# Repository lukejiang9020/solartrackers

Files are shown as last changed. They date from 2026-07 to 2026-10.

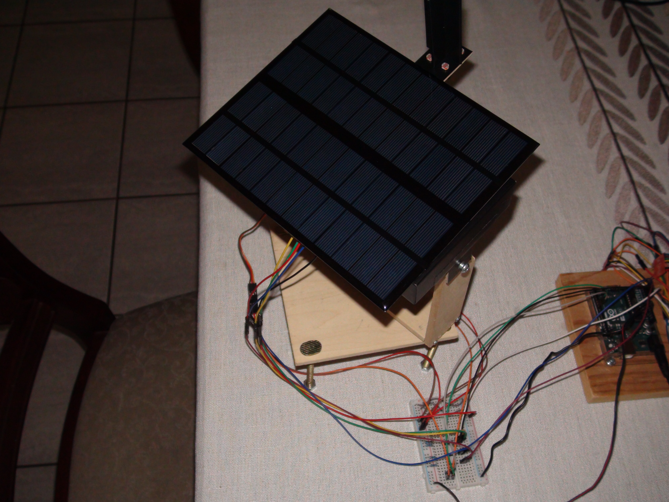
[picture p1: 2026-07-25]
imgs/DSC03407.JPG

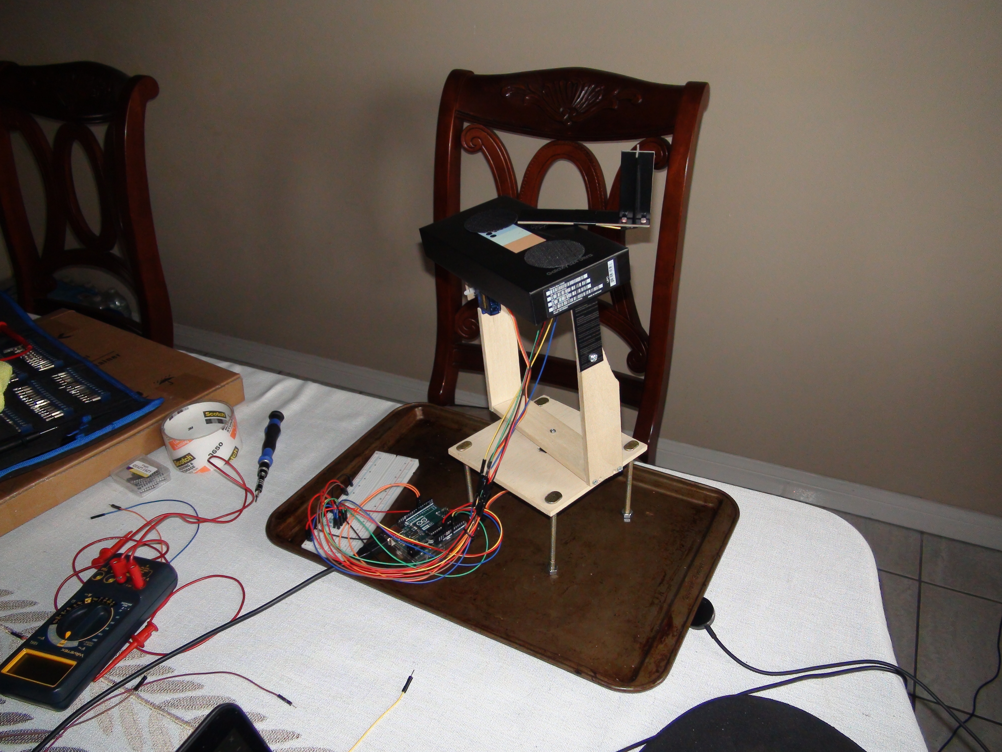
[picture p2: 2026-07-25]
imgs/DSC03404.JPG

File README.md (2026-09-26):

# Solar Tracking Project

## Introduction

Constructed and planned over the summer of 2026, this solar tracker distinguishes itself from the plethora of other solar tracker designs found on the internet. What started out as a replica of a pre-existing solar tracker design has morphed into one that is far more efficient, practical, and unique compared to ones in many other projects.

## Usage

Head over to [Solar Tracking Project](https://lukejiang9020.github.io/solartrackers) to see the process of designing the solar tracker, and results from experiments conducted on energy absorption from sunrise to sunset.

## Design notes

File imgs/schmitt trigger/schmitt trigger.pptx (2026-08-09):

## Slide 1

VCC = 13 V

LDR

Vin

+

100K Ω

1K Ω

100K Ω

100K Ω

100K Ω

Vout

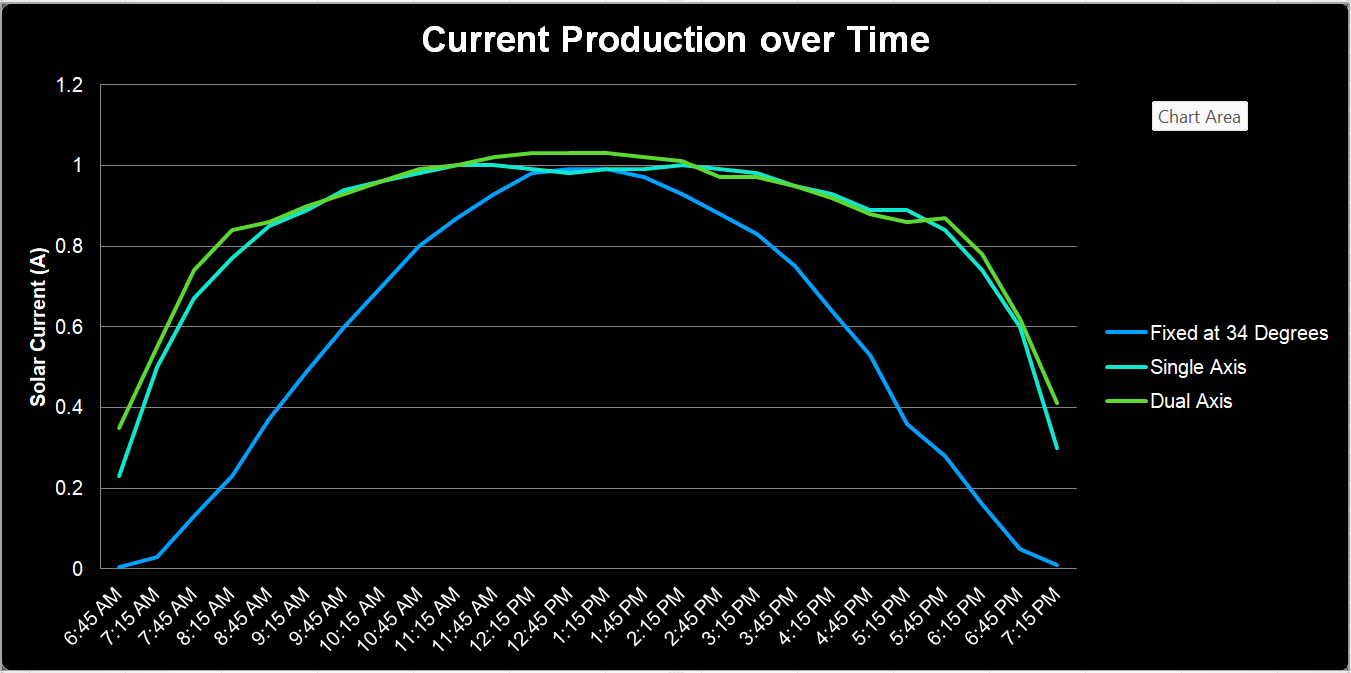
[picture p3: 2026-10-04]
imgs/energy_graph.png

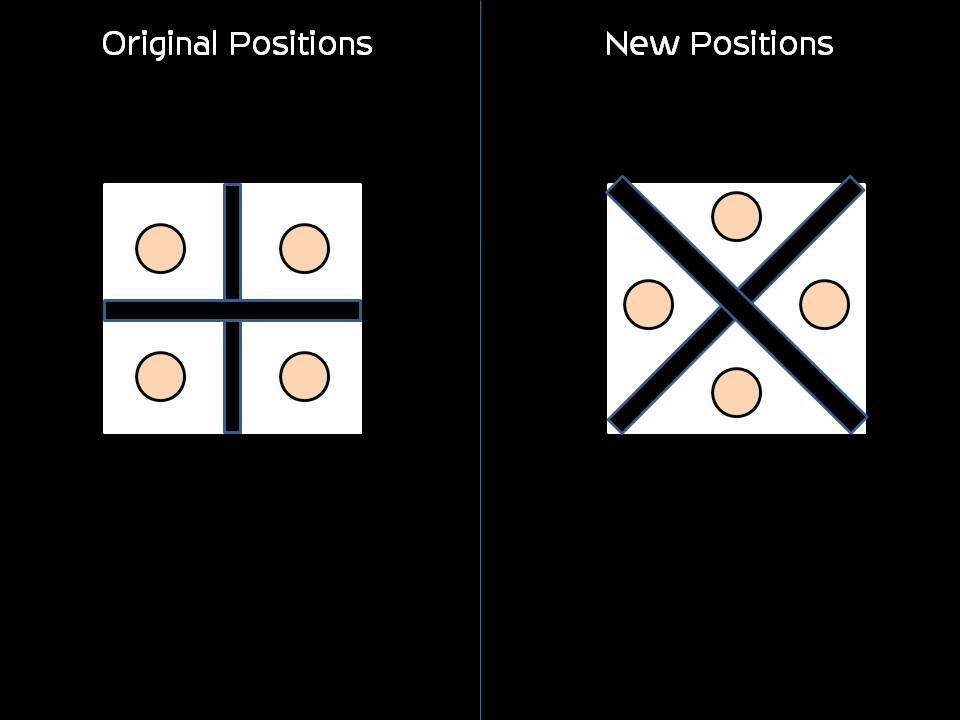
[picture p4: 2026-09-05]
imgs/ldr_positions.jpg

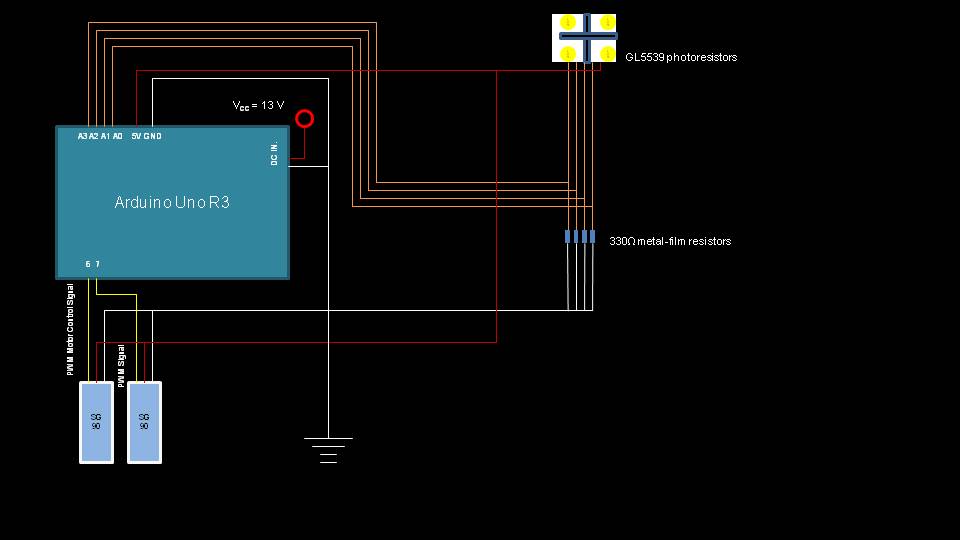
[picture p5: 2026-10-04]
imgs/block_diagram.jpg

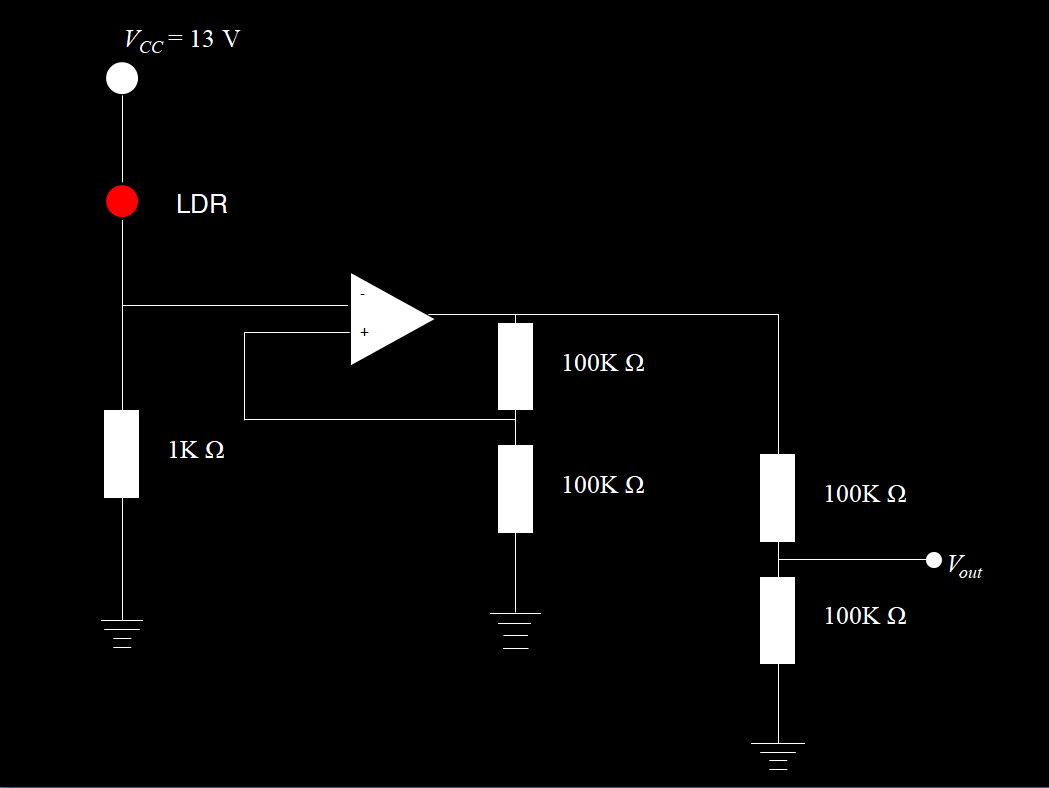
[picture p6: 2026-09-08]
imgs/schmitt_trigger.png

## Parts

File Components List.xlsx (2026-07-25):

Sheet: List of Items
Component Name | Price (ea) | Qty. | Purchase Link
Arduino UNO Rev3 | $33.99 | 1 | https://store.arduino.cc/products/arduino-uno-rev3
100 Values 1000PCS Resistor Kit 0 Ohm to 5.6 Mohm | $9.99 | 1 | https://www.amazon.com/ONJYHK-100Values-Resistor-Resistors-Assortment/dp/B0GJYDKNPC
5 Mohm LDR | $5.49 | 4 | https://www.amazon.com/Photoresistor-Resistor-Light-Dependent-Photoconductor-Sensitive/dp/B08QRRG4SN
20W 12V Solar Panel Kit (with charging controller) | $32.99 | 1 | https://www.amazon.com/SOLPERK-Maintainer-Waterproof-Controller-Adjustable/dp/B08GX19KT9
12V 10Ah LiFePo4 battery | $39.99 | 1 | https://www.amazon.com/Lithium-LiFePO4-Rechargeable-Maintenance-Free-Lighting/dp/B097BRKCQP
2 pcs SG90 Micro-servo motors | $4.99 | 1 | https://www.amazon.com/Control-Raspberry-Helicopter-Airplane-Controls/dp/B0DFKPVRC2
10pcs LM339 Quad Differential Comparator | $7.99 | 1 | https://www.amazon.com/Bridgold-Differential-Comparator-Voltage-Digital/dp/B08QN8FCXB
Taiss 40pcs potentiometer | $8.66 | 1 | https://www.amazon.com/Taiss-Potentiometer-potentiometers-Assortment-Terminals/dp/B0B3126K2M/
10 pcs L293D IC | $8.99 | 1 | https://www.amazon.com/ALLECIN-L293-L293D-Push-Pull-Controllers/dp/B0CBKC334V
Breadboard | $7.89 | 1 | https://www.amazon.com/Breadboards-Solderless-Breadboard-Distribution-Connecting/dp/B07DL13RZH
Diodes | $5.99 | 1 | https://www.amazon.com/BOJACK-Switching-IN4148-Electronic-Silicon/dp/B07Q4F3Y5W
Chanzon Step-Down Regulator | $5.99 | 1 | https://www.amazon.com/Chanzon-LM2596T-5-0-Step-Down-Regulator-Transistor/dp/B08M3HB75N
Total Price | $172.95
Amazon Total Cost | $138.96
NOTE: This list does NOT factor in sales tax or shipping costs.

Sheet: Calculations
Solar Panel Current | 0.1 | A
Arduino Uno Rev3 | 0.07 | A
SG90 motors | 1.2 | A
LDR sensors | 0.04 | A
Total | 1.31 | A

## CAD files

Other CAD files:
Solar_Tracker.dwg
Original_Tracker.dwg

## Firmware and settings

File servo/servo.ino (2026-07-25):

// Servo motor solar tracker
// Copyright (C) 2026 Luke Jiang
#include <Servo.h>
#include <avr/sleep.h>
#include <avr/interrupt.h>
//Initialize variables    

constexpr int ldrtopright = 0;
constexpr int ldrtopleft = 1;
constexpr int ldrbottomright = 2;
constexpr int ldrbottomleft = 3;


int topleft = 0;
int bottomleft = 0;
int topright = 0;
int bottomright = 0;
int limitUD = 0;
int limitLR = 0;

//Declare two servos
Servo servo_updown;
Servo servo_rightleft;

constexpr int threshold_value = 50;
constexpr float threshold_reset = 76.3;           //measurement sensitivity

// constexpr int lightPin = 2;

// volatile bool wakeFlag = false;

void setup()
{
  Serial.begin(9600);                                //serial connection setup  //opens  serial port, sets data rate to 9600 bps
  Serial.println("CLEARDATA");                       //clear  all data that’s been place in already
  Serial.println("LABEL,t,voltage,current,power,Mode");   //define the column headings (PLX-DAQ command)
  

  servo_updown.attach(6);             //Servo motor up-down movement
  servo_rightleft.attach(7); 
  initialize();    //Servo motor right-left movement
}

void loop()
{
//  pv_power();

    float volt = analogRead(A5)*5.0/1023;
    float voltage = 2*volt;                //  Volt=(R1/R1+R2)*Voltage / R1=R2=10Ohms  => voltage=2*volt)
    float current = voltage/20;            //  I=voltage/(R1+R2) 
    float power  = voltage*current;
    if (volt == 0) {
      Serial.println("Please connect solar panel on pin A5!");
    } else {
      Serial.print("DATA,TIME,"); // PLX-DAQ command
      Serial.print(voltage);    //send the voltage to serial port
      Serial.print(",");
      Serial.print(current);    //send the current to serial port
      Serial.print(",");
      Serial.print(power);  //send the power to serial port
      Serial.print(",");
    }
    automaticsolartracker();
    // testMotor();
}

void initialize() {
  if (servo_rightleft.read() < 90) {
    for (int pos = servo_rightleft.read(); pos < 90; pos++) {
      servo_rightleft.write(pos);
      delay(30);
    }
  } else {
    for (int pos = servo_rightleft.read(); pos > 90; pos--) {
      servo_rightleft.write(pos);
      delay(30);
    }
  }

  if (servo_updown.read() < 90) {
    for (int pos = servo_updown.read(); pos < 90; pos++) {
      servo_updown.write(pos);
      delay(30);
    }
  } else {
    for (int pos = servo_updown.read(); pos > 90; pos--) {
      servo_updown.write(pos);
      delay(30);
    }
  }
}

void automaticsolartracker() {

     topleft = analogRead(ldrtopleft);
     bottomright = analogRead(ldrbottomright);
     topright = analogRead(ldrtopright);
     bottomleft = analogRead(ldrbottomleft);
     // calculating average

     // calculating average
     int avgtop = (topright + topleft) / 2;     //average  of top LDRs
     int avgbot = (bottomright + bottomleft) / 2;     //average of bottom LDRs
     int avgleft = (topleft + bottomleft) / 2;    //average of left LDRs
     int avgright  = (topright + bottomright) / 2;   //average of right LDRs

     int diffelev = avgtop - avgbot;
     int diffazi = avgright - avgleft;
     
     
      if (diffazi >= threshold_value && servo_rightleft.read() <= 180){
          servo_rightleft.write((servo_rightleft.read() + 1.0));
      }
      if (abs(diffazi) >= threshold_value && diffazi < 0 && servo_rightleft.read() > 0) { 
          servo_rightleft.write((servo_rightleft.read() - 1.0));
      }
             
      //up-down movement of solar tracker

      if (diffelev >= threshold_value && servo_updown.read() <= 150) { 
          servo_updown.write((servo_updown.read() + 1.0));
      }
      if (abs(diffelev) >= threshold_value && diffelev < 0 && servo_updown.read() > 30) {
          servo_updown.write((servo_updown.read() - 1.0));
      }
           
 }

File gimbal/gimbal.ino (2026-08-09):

// Gimbal Solar Tracker - by Luke Jiang
// Copyright (C) 2026 Luke Jiang. All Rights Reserved.
// final version

constexpr int ldrtop = 1;
constexpr int ldrbottom = 2;
constexpr int ldrleft = 3;
constexpr int ldrright = 0;
constexpr int ldrNight = 4;

int top = 0;
int bottom = 0;
int left = 0;
int right = 0;
int night = 0;
int limitUD = 0;
int limitLR = 0;
int isNight = 0;

constexpr int threshold_value = 100;
constexpr int threshold_reset = 76.3;

void setup() {
  // put your setup code here, to run once:
  delay(10000);
  Serial.begin(9600);
  Serial.println("BEGIN");
  pinMode(10, OUTPUT); // horizontal - move right
  pinMode(11, OUTPUT); // horizontal - move left
  pinMode(12, OUTPUT); // vertical - move up
  pinMode(13, OUTPUT); // vertical - move down
  pinMode(9, INPUT); // vertical - 90 deg (topmost)
  pinMode(8, INPUT); // vertical - 0 deg (second top-most)
  pinMode(7, INPUT); // black and yellow wired limit sensor
  pinMode(6, INPUT); // bottom left
  initialize();
}

void stopVertical() {
  digitalWrite(10, LOW);
  digitalWrite(11, LOW);
}

void stopHorizontal() {
  digitalWrite(12, LOW);
  digitalWrite(13, LOW);
}

void loop() {
  // put your main code here, to run repeatedly:
  wormgear();
}

void initialize() {
  Serial.println("Initialization begin!");
  stopHorizontal();
  while (digitalRead(8) == HIGH) {
    digitalWrite(11, HIGH);
    digitalWrite(10, LOW);
  }
  Serial.println("Limit sensor has been reached!");

  stopVertical();
  delay(100);

  Serial.print("Pin 8 reading: ");
  Serial.println(digitalRead(8));
  unsigned long startTime = millis();
  while (millis() - startTime < 5000) {
    Serial.println("Reversing motor direction...");
    digitalWrite(11, LOW);
    digitalWrite(10, HIGH);
  }
  stopVertical();
  while (digitalRead(7) == HIGH) {
    digitalWrite(12, LOW);
    digitalWrite(13, HIGH);
  }
  unsigned long start = millis();
  while (millis() - start < 7000) {
    digitalWrite(12, HIGH);
    digitalWrite(13, LOW);
  }
  stopHorizontal();
  Serial.println("Initialization STOP!");
  delay(5000);
  Serial.println("GO!");
}

void wormgear() {
  top = analogRead(ldrtop);
  bottom = analogRead(ldrbottom);
  left = analogRead(ldrleft);
  right = analogRead(ldrright);
  night = analogRead(ldrNight);

  Serial.print("Top: ");
  Serial.println(top*5.0/1023);
  Serial.print("Bottom: ");
  Serial.println(bottom*5.0/1023);
  Serial.print("Left: ");
  Serial.println(left*5.0/1023);
  Serial.print("Right: ");
  Serial.println(right*5.0/1023);
  // delay(4000);
  // Serial.print("Pin 9 reading: ");
  // Serial.println(digitalRead(8));

  
  int diffelev = top - bottom;
  int diffazi = right - left;


  // normal operating conditions
  if (diffazi >= threshold_value && digitalRead(8) == HIGH) { // ensures limit sensor has not been activated
    // moves solar panel up
    digitalWrite(10, HIGH);
    digitalWrite(11, LOW);
  } else if (abs(diffazi) >= threshold_value && diffazi < 0 && digitalRead(9) == HIGH) {
    // moves solar panel down
    digitalWrite(10, LOW);
    digitalWrite(11, HIGH);
  } else {
    stopVertical(); // sends LOW signal to both pins 10 and 11
  }



  if (diffelev >= threshold_value && digitalRead(7) == HIGH) {
    // digitalWrite(10, LOW);
    // digitalWrite(11, LOW);
    digitalWrite(12, HIGH);
    digitalWrite(13, LOW);
  } else if (abs(diffelev) >= threshold_value && diffelev < 0 && digitalRead(6) == HIGH) {
    // digitalWrite(10, LOW);
    // digitalWrite(11, LOW);
    digitalWrite(12, LOW);
    digitalWrite(13, HIGH);
  } else {
    stopHorizontal();
  }

  if (digitalRead(7) == LOW) {
    unsigned long start_time = millis();
    while (digitalRead(7) == LOW) {
      Serial.println("Reversing motor direction...");
      while (millis() - start_time < 4000) {
        digitalWrite(12, HIGH);
        digitalWrite(13, LOW);
      }
        Serial.println("Motor STOP!");
        stopHorizontal();
        delay(30000);
    }
  }

  if (digitalRead(6) == LOW) {
    unsigned long starting = millis();
    while (digitalRead(6) == LOW) {
      Serial.println("Reversing motor direction...");
      while (millis() - starting < 4000) {
        digitalWrite(12, LOW);
        digitalWrite(13, HIGH);
      }
        Serial.println("Motor STOP!");
        stopHorizontal();
        delay(30000);
    }
  }
  
  while (digitalRead(8) == LOW && !isNight) {
    Serial.println("Limit sensor reached!");
    digitalWrite(10, HIGH);
    digitalWrite(11, LOW);
    if (digitalRead(8) == HIGH) {
      Serial.println("Motor STOP!");
      stopVertical();
      delay(100);
      unsigned long timeBegin = millis();
      while (millis() - timeBegin < 17000) {
        digitalWrite(12, HIGH);
        digitalWrite(13, LOW);
      }
      stopHorizontal();
      delay(10000);
    }
  }

  while (digitalRead(9) == LOW && !isNight) {
    Serial.println("Limit sensor reached!");
    digitalWrite(10, LOW);
    digitalWrite(11, HIGH);
    if (digitalRead(9) == HIGH) {
      Serial.println("Motor STOP!");
      stopVertical();
      delay(10000);
    }
  }
}

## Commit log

2026-08-29 Change website to white-on-black theme
    [Voltage_discharge.xlsx]
2026-09-08 Major cleanup of CSS rules, delete redundant files, and modify content of arduino.html
2026-09-15 Update arduino.html content
2026-09-21 Update content on arduino.html
2026-09-26 Update README and arduino.html
2026-10-02 Add CAD rendering
2026-10-02 Update CAD renderings
2026-10-12 Major update to arduino.html
2026-10-18 Add new circuit diagram
2026-10-18 Update CAD drawing for circuit diagram
2026-10-18 Update circuit diagram
2026-10-19 Update CAD viewer styling
2026-10-23 Change styling of circuit diagram
2026-10-23 Create interactive circuit diagram for original tracker design
2026-10-24 Update circuit diagram PDF files
2026-11-08 Update CAD drawings
2026-11-14 Update style of buttons
